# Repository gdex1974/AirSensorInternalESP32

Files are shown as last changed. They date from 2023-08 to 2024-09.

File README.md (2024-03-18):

# Air Quality Sensor - internal unit

## Description
The Air Quality Sensor project contains two parts:
- [External unit](https://github.com/gdex1974/AirSensorExternalESP32) - the main unit placed inside the building
- Internal unit - the unit placed outside the building

The internal unit is equipped with e-Ink display and shows the temperature, humidity and pressure alongside with PM1/2.5/10 measurements from external unit and its own internal sensors. It's powered by 18500 accumulator and receive data from the external unit via Esp-Now transport protocol.
This unit is based on Firebeetle-ESP32 board, with the firmware based on ESP-IDF framework. The board was chosen due to 32K oscillator for RTC and low power consumption.

## Hardware

- [Firebeetle-ESP32](https://wiki.dfrobot.com/FireBeetle_ESP32_IOT_Microcontroller(V3.0)__Supports_Wi-Fi_&_Bluetooth__SKU__DFR0478) main microcontroller board
- [SPS30](https://botland.store/air-quality-sensors/15062-dust-air-sensor-sps30-pm10-pm25-pm4--5904422366094.html) particulate matter sensor
- [BME280](https://botland.store/pressure-sensors/11803-bme280-humidity-temperature-and-pressure-5904422366179.html) temperature, humidity and pressure sensor
- [Pololu Mini MOSFET Switch](https://www.pololu.com/product/2810) low voltage module switch
- [Pololu U1V10F5](https://www.pololu.com/product/2564) 5V step-up module
- [18650 battery case](https://botland.store/battery-holders/5242-cell-holder-for-1x-18650-5904422333393.html) 18650 battery case
- [18650 accumulator](https://botland.store/li-ion-batteries/15216-18650-li-ion-samsung-inr18650-35e-3500mah-5904422343071.html) 18650 accumulator
- [3,7" WaveShare e-ink display](https://www.waveshare.com/wiki/3.7inch_e-Paper_HAT) 3,7" WaveShare e-ink display
- [2x20 2,54mm DIP header](https://www.kiwi-electronics.com/en/40-pin-male-header-2x20-1174) 2x20 2,54mm DIP header
- [Prototyping board 40x60mm 2,54mm pitch](https://www.kiwi-electronics.com/en/prototyping-board-4x6cm-2-54mm-pitch-3828) Prototype board 40x60mm 2,54mm pitch

## Software

- [esp-idf](https://github.com/espressif/esp-idf/releases/tag/v4.4.5) main framework
- [general-support-library](https://github.com/gdex1974/embedded-general-support-library) common embedded library
- [SimpleDrivers](https://github.com/gdex1974/embedded-simple-drivers) simple embedded drivers for SPS30 and BME280 sensors

## Setup

All parts of the unit are fixed on frame and covered by external cover. The frame is designed to fit the Firebeetle board, switch, step-up converter, BME280 and SPS30 sensors. It's attached to battery case and the whole module is placed into the external cover. The fame and cover parts are 3D printed.
Connection schema:
- SPS30 sensor is connected to the UART2 port of the Firebeetle board.
  - `VCC` pin of the sensor is connected to the +5V output of the step-up converter
  - `RX` pin of the sensor is connected to the `IO26` pin of the board
  - `TX` pin of the sensor is connected to the `IO27` pin of the board
  - `SEL` pin of the sensor is not connected
  - `GND` pin of the sensor is connected to the `GND` pin of the board
- BME280 module is connected to the I2C port of the Firebeetle board
  - `SDA` pin of the sensor is connected to the `IO21` pin of the board
  - `SCL` pin of the sensor is connected to the `IO22` pin of the board
  - `GND` pin of the sensor is connected to the `GND` pin of the board
  - `VCC` pin of the sensor is connected to the `3V3` pin of the board
- Pololu 2810 switch is mounted under the main board:
  - `GND` connected to the GND pin of the board
  - `Enable` pin connected to the IO13 pin of the Firebeetle board
  - `VIN` pin connected to the battery+ of the Firebeetle board
  - `VOUT` pin connected to the + input of the step-up converter
- step-up converter's is fixed into separated place on the frame under the board
  - `VIN` is connected to the VBAT pin of the Firebeetle board
  - `GND` is connected to the GND pin of the Firebeetle board
  - `VOUT`is connected to the VCC pin of the SPS30 sensor
- e-ink display is connected to the SPI port of the Firebeetle board. It's attached to the 2x20 DIP header soldered on the protoboard to emulate the Raspberry PI 40-pin header. To make it, the protoboard have to be cut to the 3x20 size and the header should be soldered to the board. The cords to the display are soldered to the socket (the 1st pin is top left):
  - `CS`: pin 24 of the header is connected to the `IO25` pin of the board
  - `DC`: pin 22 of the header is connected to the `IO4` pin of the board
  - `RST`: pin 11 of the header is connected to the `IO15` pin of the board
  - `BUSY`: pin 18 of the header is connected to the `IO16` pin of the board
  - `CLK`: pin 23 of the header is connected to the `IO18` pin of the board
  - `DIN`: pin 19 of the header is connected to the `IO23` pin of the board
  - `GND` pin 6 (possibly 9, 14, 20, 25, 30, 34, 39) of the socket is connected to the `GND` pin of the board
  - `3.3V` pin 1 of the socket is connected to the `3V3` pin of the board

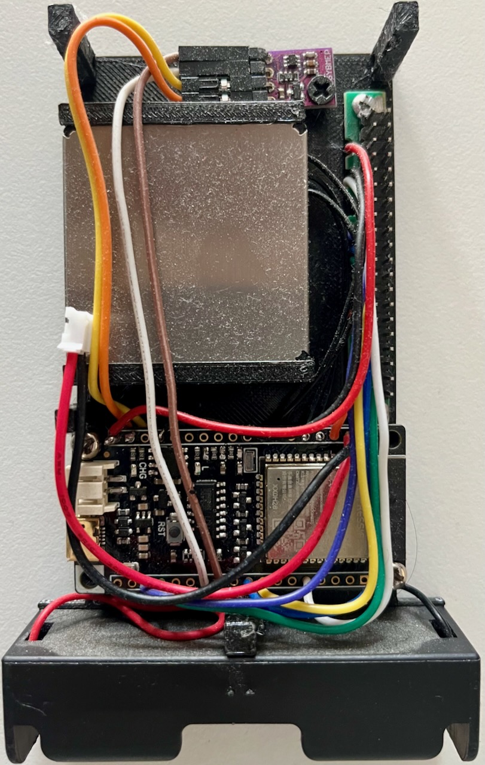
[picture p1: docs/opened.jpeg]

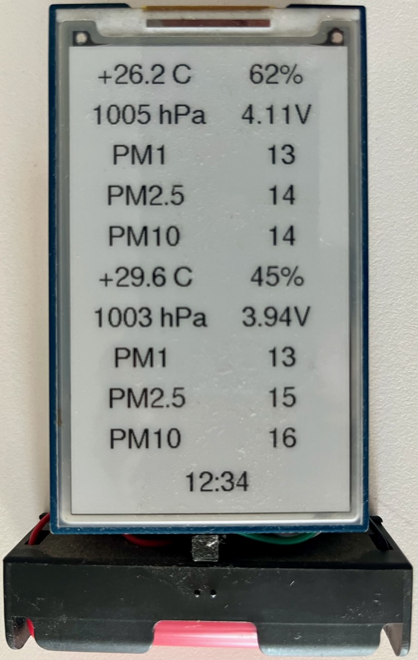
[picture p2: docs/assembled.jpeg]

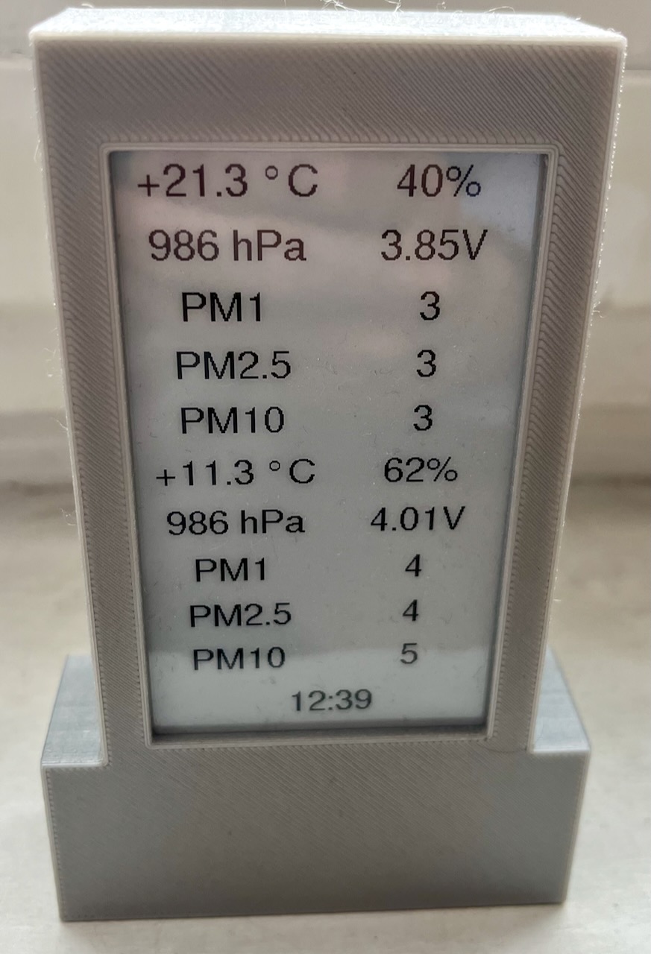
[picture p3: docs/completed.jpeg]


## Firmware

The firmware is based on ESP-IDF framework (tested version is 4.4.5) and is written in C++ language. The main task is to show the data from internal sensors alongside with the ones received from the external unit via Esp-Now protocol. The firmware is divided into several modules:

- components - contains the code of the external unit
  - general-support library - contains the code for general support functions, obtained from this repository.
  - SimpleDrivers - contains the code for the SPS30, BME280 and e-Ink display drivers, obtained from this repository.
- main - contains the main code of the external unit's firmware
  - AppConfig - contains the code for the application's configuration
  - AppMain - contains the app_main() function and hosts the controller object
  - DustMonitorController - contains the code for the controller class handling the main logic of the firmware
  - DustMonitorView - contains the code for the class providing the data for the e-Ink display
  - EspNowTransport - contains the code for the communication with the main unit based on Esp-Now protocol
  - PTHProvider - contains the code for the class providing the data from BME280 sensor
  - SPS30DataProvider - contains the code for the class providing the data from SPS30 sensor
  - WiFiManager - contains the code for the class providing the Wi-Fi connection management
- CMakeLists.txt - main CMake file for the firmware
- sdkconfig - default configuration file for the ESP-IDF framework.

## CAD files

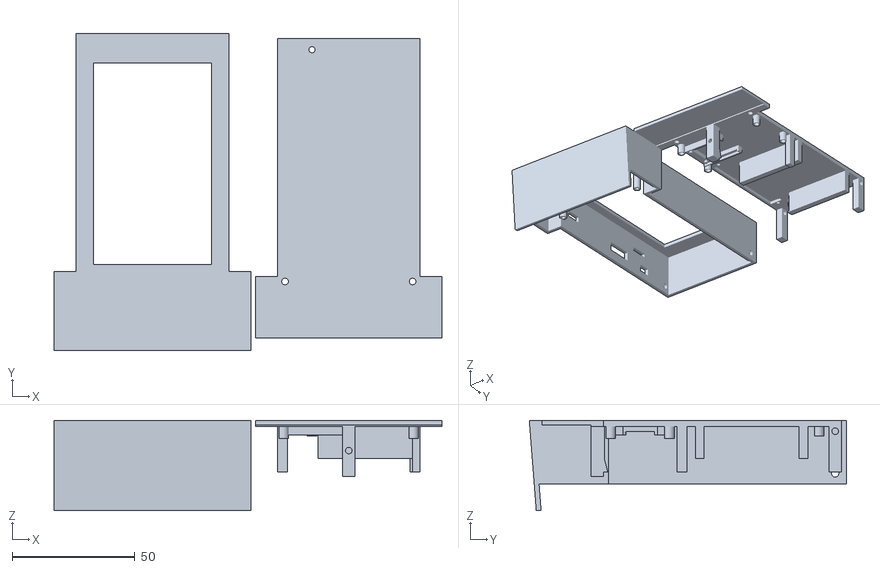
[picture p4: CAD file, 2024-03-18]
docs/PMSensorCaseInternal.stl
158.2 x 129.4 x 36.8

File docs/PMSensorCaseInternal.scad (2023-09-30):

$fn=180;

module fireBeetleD()
{
    height = 7;
    width = 29;
    length = 58;
    radius = 2;
    delta = 5;
    x = length - radius;
    y = width - radius;
    z = height;
    hole_diameter = 2.7;
    linear_extrude(height = z) hull() {
        translate([(- x / 2) + (radius / 2), (- y / 2) + (radius / 2), 0])
            circle(r = radius);

        translate([(x / 2) - (radius / 2), (- y / 2) + (radius / 2), 0])
            circle(r = radius);

        translate([(- x / 2) + (radius / 2), (y / 2) - (radius / 2), 0])
            circle(r = radius);

        translate([(x / 2) - (radius / 2), (y / 2) - (radius / 2), 0])
            circle(r = radius);
    }
    translate([-(length - delta) / 2, (width - delta) / 2, height]) cylinder(d = hole_diameter, h = 7, center = false);
    translate([(length - delta) / 2, -(width - delta) / 2, height]) cylinder(d = hole_diameter, h = 7, center = false);
    translate([-(length - delta) / 2, -(width - delta) / 2, height]) cylinder(d = hole_diameter, h = 7, center = false);
    translate([(length - delta) / 2, (width - delta) / 2, height]) cylinder(d = hole_diameter, h = 7, center = false);
}

module bme280i2c()
{
    hole_diameter = 2.7;
    cube([10.5, 13.5, 4]);
    translate([8, 11, - 5]) cylinder(d = hole_diameter, h = 12, center = false);
    translate([3.5, 11, - 10]) cylinder(d = 2.5, h = 8, center = false);
    translate([(10.5 - 8) / 2, 1, 4])cube([8, 2, 6]);
}

module PMS9003M()
{
    x = 40;
    y = 48;
    z = 12;
    radius = 3.5;
    hole_diameter = 2.7;
    union() {
        difference() {
            linear_extrude(height = z) hull() {
                // place 4 circles in the corners, with the given radius
                translate([(- x / 2) + (radius), (- y / 2) + (radius), 0])
                    circle(r = radius);

                translate([(x / 2) - (radius), (- y / 2) + (radius), 0])
                    circle(r = radius);

                translate([(- x / 2) + (radius), (y / 2) - (radius), 0])
                    circle(r = radius);

                translate([(x / 2) - (radius), (y / 2) - (radius), 0])
                    circle(r = radius);
            }
            for (i = [0:1]) rotate([0, 0, i * 180]) translate([(x / 2) - (radius), (y / 2) - (radius), 0]) {
                cylinder(h = 13, r = 3.5, center = false);
                translate([- 3.5, 0, 0])cube([7, 3.5, 13]);
                translate([0, - 3.5, 0]) cube([3.5, 7, 13]);
            }
        }
        translate([0, 0, (z - 1) / 2])linear_extrude(height = 1) hull() {
            // place 4 circles in the corners, with the given radius
            translate([(- x / 2) + (radius), (- y / 2) + (radius), 0])
                circle(r = radius);

            translate([(x / 2) - (radius), (- y / 2) + (radius), 0])
                circle(r = radius);

            translate([(- x / 2) + (radius), (y / 2) - (radius), 0])
                circle(r = radius);

            translate([(x / 2) - (radius), (y / 2) - (radius), 0])
                circle(r = radius);
        }
        for (i = [0:1]) rotate([0, 0, i * 180]) translate([(x / 2) - (radius), (y / 2) - (radius), 0]) {
            cylinder(h = 12, d = hole_diameter, center = false);
        }
        translate([x / 2 - 28 - 4, - y / 2 + 7.5, 12]) cube([8, 9, 5]);
        translate([x / 2 - 28, 36 - y / 2, 12]) difference() {
            cylinder(d = 20, h = 5);
            rotate([0, 0, 135])translate([- 2.5, 0, - 1])cube([5, 10, 10]);
            translate([0, 0, - 1])cylinder(d = 12, h = 7);
        }
    }
}

sps30Width = 40.9;
sps30Depth = 40.8;
sps30Height = 12.5;
module sps30()
{
    cube([sps30Depth, sps30Width, sps30Height]);
    bigInletWidth = 6.6;
    bigInletHeight = 3.8;
    translate([sps30Depth, sps30Width - bigInletWidth - 2.2, 8.2])cube([4, bigInletWidth, bigInletHeight]); // big inlet
    smallInletWidth = 10;
    smallInletHeight = 2;
    translate([sps30Depth, sps30Width - smallInletWidth - 5.2, - 0.2])cube([4, smallInletWidth, smallInletHeight]);
    // small inlet
    outletWidth = 14.8;
    outletHeight = 5;
    translate([sps30Depth, 5.5, 5.8])cube([4, outletWidth, outletHeight]); //outlet
}


module stepup5V()
{
    union() {
        cube([18, 26, 1.5]);//3.8
        translate([2, - 1, - 1.5 - 1.4 + 0.6]) cube([14, 21.7, 2.3 + 1.4]);
    }
}

module epd37()
{
    plateHeight = 1.8;
    shift = 0.6;
    union() {
        cube([58, 96.5, plateHeight]);
        translate([5, 5, - 3]) cube([48, 82, 3]);
        translate([52, 49.4, plateHeight]) cube([5.7, 20, 6]);
        translate([shift, 33.6, plateHeight]) cube([5, 51.2, 20.2]);
        translate([shift, 33.6 - (60 - 51.2) / 2, 0.3 + 18.6]) cube([7, 60, 1.5]);
        translate([shift + 4.2, 33.6 - (60 - 51.2) / 2 + 3, 0.3 + 18.6 - 5.5])cylinder(d = 1.8, h = 9);
        translate([shift + 4.2, 33.6 - (60 - 51.2) / 2 + 3 + 54, 0.3 + 18.6 - 5.5])cylinder(d = 1.8, h = 9);
        translate([shift + 4.8, 33.6, 0.3 + 18.6 + 1.5]) cube([3, 51.2, 1.4]);
    }
}

module LiIonCase()
{
    base = 55;
    width = 76;
    height = 20;
    depth = 21;
    hole_diameter = 2.7;
    cube([depth, width, height]);
    translate([depth / 2, width / 2, - 6]) cylinder(d = hole_diameter, h = 6);
}

basePlateThickness = 2.4;
internalHeight = 122;
internalBatteryHeight = 25;
internalBatteryWidth = 76;
internalMainWidth = 58;
internalSpaceHeignt = 21.6;
basePlateShiftZ = 18;

module mainFrame()
difference() {
    union() {
        color("magenta") translate([0, - internalBatteryHeight, basePlateShiftZ])cube([internalMainWidth,
            internalHeight, basePlateThickness]);
        color("magenta") translate([- 9, - internalBatteryHeight, basePlateShiftZ])cube([internalBatteryWidth,
            internalBatteryHeight, basePlateThickness]);
        color("green") translate([2, 5, 14.5]) cube([26, 20, 4]);
        color("magenta") translate([2.5, 3, 13]) {
            cylinder(d = 4, h = 6);
            translate([0, 24, 0]) cylinder(d = 4, h = 6);
            translate([53, 0, 0]) cylinder(d = 4, h = 6);
            translate([53, 24, 0]) cylinder(d = 4, h = 6);
        }

        translate([12.7 + 1.3, 36.7 + 51.3, 12.5]) cylinder(d = 4, h = 6);
        translate([16.5, 38.5 - 1, 4.9]) cube([41.5, 3.6, 13.1]);
        translate([17.5, 35 + 44.8, 4.9]) cube([40.5, 3.6, 13.1]);

        color("magenta") translate([- 1 + 27.5, - 5 - 0.5, - 1.5 + 0.2 - 1.1]) union() {
            cube([5, 6, internalSpaceHeignt]);
            translate([0, 1, 6]) rotate([- 75, 0, 0]) cube([5, 6, 5]);
        }

        color("magenta") {
            translate([0, 92, - 0.6]) cube([4, 5, 20]);
            translate([54, 92, - 0.6]) cube([4, 5, 20]);
            translate([55, 30, - 1]) cube([3, 4, 20]);
        }
    }
    union() {
        color("green")translate([17.2, 40, 5.5]) sps30();
        translate([67, - 5, - basePlateThickness])rotate([0, - 90, 90])LiIonCase();

        translate([1, 0, - basePlateThickness])epd37();

        color("red") translate([29, 15, 6])rotate([0, 0, 0])fireBeetleD();
        color("blue")translate([25, 96, 14])rotate([0, 180, 90]) bme280i2c();

        color("cyan") translate([27, 24, 15.8]) rotate([0, 180, 90]) difference() {
            stepup5V();
            translate([(18 - 1) - 1.2, 24.3 - 1 - 1.5, - 2]) cylinder(d = 1.9, h = 4, center = false);
            translate([(0 + 1) + 1.2, 24.3 - 1 - 1.5, - 2]) cylinder(d = 1.9, h = 4, center = false);
        }
    }
    translate([3, - 2, 11])rotate([0, 0, 0])cylinder(d = 2.7, h = 10);
    translate([55, - 2, 11])rotate([0, 0, 0])cylinder(d = 2.7, h = 10);
    translate([- 1, 94.5, 16])rotate([0, 90, 0])cylinder(d = 2.7, h = 10);
    translate([54, 94.5, 16])rotate([0, 90, 0])cylinder(d = 2.7, h = 10);
}

frontThickness=2;
wallThickness=2;

wallHeight=internalSpaceHeignt+frontThickness+basePlateThickness;
widthDiff2=(internalBatteryWidth-internalMainWidth)/2;
internalGap=0.2;
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

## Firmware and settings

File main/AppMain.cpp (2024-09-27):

#include "DustMonitorController.h"
#include "PersistentStorage.h"
#include "TimeFunctions.h"
#include "AppConfig.h"

#include "SpiDevice.h"
#include "display/EpdInterface.h"

#include "esp32-esp-idf/I2CBus.h"
#include "esp32-esp-idf/PacketUartImpl.h"
#include "esp32-esp-idf/GpioPinDefinition.h"
#include "esp32-esp-idf/SpiBus.h"

#include <esp_attr.h>
#include <esp_sleep.h>
#include <esp_system.h>
#include <soc/rtc.h>
#include <nvs_flash.h>

#include "Debug.h"

namespace
{
constexpr uint32_t rtcCalibrationFactor = (1 << 19);

constexpr uint32_t wakeupDelay = 870000;

RTC_DATA_ATTR std::array<uint8_t, 2048> persistentArray;
std::optional<embedded::PersistentStorage> persistentStorage;

struct MainData
{
    uint32_t wakeupCounter = 0;
    uint32_t rtcCalibrationResult = 0;
    timeval rtcTimeBeforeDeepSleep { .tv_sec = 0, .tv_usec=0 };
    uint64_t rtcSlowTicksBeforeDeepSleep = 0;
};

class ControllersHolder
{
public:
    ControllersHolder(embedded::PersistentStorage &storage, int spiBusNum,
                      int serialPortNum, int8_t address)
            : i2CBus(0)
              , i2CDevice(i2CBus, address)
              , uartDevice(serialPortNum)
              , sps30Uart(uartDevice)
              , spiBus(spiBusNum)
              , spiDevice(spiBus)
              , epdHAL(spiDevice, rstPin, dcPin, csPin, busyPin)
              , controller(storage, sps30Uart, i2CDevice, epdHAL)
    {
        i2CBus.init(AppConfig::SDA, AppConfig::SCL, 400000);
        spiBus.init(sckPin, misoPin, mosiPin);
    }
    DustMonitorController& getController() { return controller; }
private:
    embedded::I2CBus i2CBus;
    embedded::I2CHelper i2CDevice;
    embedded::PacketUart::UartDevice uartDevice;
    embedded::PacketUart sps30Uart;
    embedded::SpiBus spiBus;
    embedded::SpiDevice spiDevice;
    embedded::GpioPinDefinition rstPin{AppConfig::epdResetPin};
    embedded::GpioPinDefinition dcPin{AppConfig::epdDcPin};
    embedded::GpioPinDefinition csPin{AppConfig::epdCsPin};
    embedded::GpioPinDefinition busyPin{AppConfig::epdBusyPin};
    embedded::GpioPinDefinition sckPin{AppConfig::epdSckPin};
    embedded::GpioPinDefinition misoPin{AppConfig::epdMisoPin};
    embedded::GpioPinDefinition mosiPin{AppConfig::epdMosiPin};
    embedded::EpdInterface epdHAL;
    DustMonitorController controller;
};

std::optional<ControllersHolder> controllersHolder;

auto getMicrosecondsTillNextMinute()
{
    const int64_t microSeconds = microsecondsNow();
    const int64_t wholeMinutePast = (microSeconds / microsecondsInMinute) * microsecondsInMinute;
    return wholeMinutePast + microsecondsInMinute - microSeconds;
}

uint32_t calculateHibernationDelay()
{
    const auto timeTillNextMinute = getMicrosecondsTillNextMinute();
    DEBUG_LOG("Time till next minute:" << timeTillNextMinute)
    uint32_t delayTime;
    if (timeTillNextMinute <= wakeupDelay)
    {
        DEBUG_LOG("Too short delay " << timeTillNextMinute << " (" << wakeupDelay << "), skipping next wakeup")
        delayTime = microsecondsInMinute + timeTillNextMinute - wakeupDelay;
    }
    else
    {
        delayTime = timeTillNextMinute - wakeupDelay;
    }
    return delayTime;
}

uint32_t calibrateRtcOscillator()
{
    const uint32_t calCount = 1000;
    uint32_t caliVal;

    for (int i = 0; i < 5; ++i)
    {
        caliVal = rtc_clk_cal(RTC_CAL_32K_XTAL, calCount);
        DEBUG_LOG("Calibration " << i << ": " << embedded::BufferedOut::precision { 3 } << rtcCalibrationFactor * 1000.0f / (float)caliVal << " kHz")
    }
    return caliVal;
}

void adjustClock(MainData &mainData)
{
    if (mainData.rtcCalibrationResult != 0)
    {
        auto newCircles = rtc_time_get();
        uint64_t diffTicks = newCircles - mainData.rtcSlowTicksBeforeDeepSleep;
        auto diffMicroseconds = diffTicks * mainData.rtcCalibrationResult / rtcCalibrationFactor;
        auto timeMicroseconds =
                mainData.rtcTimeBeforeDeepSleep.tv_sec * 1000000ull +
                mainData.rtcTimeBeforeDeepSleep.tv_usec;
        timeMicroseconds += diffMicroseconds;
        const uint32_t seconds = timeMicroseconds / 1000000;
        const uint32_t microseconds = timeMicroseconds - seconds * 1000000;
        timeval timeVal { .tv_sec = static_cast<time_t>(seconds), .tv_usec= static_cast<suseconds_t>(microseconds) };
        settimeofday(&timeVal, nullptr);
        DEBUG_LOG("Calculated sleep time : " << diffMicroseconds)
    }
}

} // namespace

void setup()
{
    persistentStorage.emplace(persistentArray,esp_reset_reason() != ESP_RST_DEEPSLEEP);

    auto mainData = persistentStorage->get<MainData>("main");
    if (!mainData)
    {
        mainData.emplace();
    }

    setenv("TZ", AppConfig::timeZone.begin(), 1);
    tzset();

    const bool initialSetup = mainData->wakeupCounter++ == 0;
#ifdef DEBUG_SERIAL_OUT
    embedded::PacketUart::UartDevice::init(0, AppConfig::serial1RxPin, AppConfig::serial1TxPin, 115200);
#endif
    embedded::PacketUart::UartDevice::init(2, AppConfig::serial2RxPin, AppConfig::serial2TxPin, 115200);
    embedded::GpioPinDefinition ledPinDefinition { AppConfig::ledPin };
    embedded::GpioDigitalPin ledPin(ledPinDefinition);
    ledPin.init();
    ledPin.reset();
    controllersHolder.emplace(*persistentStorage, 2, 2, AppConfig::bme280Address);
    if (initialSetup)
    {
        DEBUG_LOG("Initial setup")
        mainData->rtcCalibrationResult = calibrateRtcOscillator();
    }
    else
    {
        adjustClock(*mainData);
    }
    if (!controllersHolder->getController().setup(!initialSetup))
    {
        DEBUG_LOG("Setup failed")
    }
    persistentStorage->set("main", *mainData);
}

[[noreturn]] void process()
{
    auto& controller = controllersHolder->getController();
    auto mainData = persistentStorage->get<MainData>("main");
    controller.process();
    controller.hibernate();
    auto delayTime = calculateHibernationDelay();
    if (controller.isMeasuring())
    {
        delayTime = std::min(delayTime, decltype(delayTime)(30 * microsecondsInSecond));
    }
    DEBUG_LOG("Next wakeup in " << delayTime / 1000 << " ms")
    gettimeofday(&mainData->rtcTimeBeforeDeepSleep, nullptr);
    mainData->rtcSlowTicksBeforeDeepSleep = rtc_time_get();
    persistentStorage->set("main", *mainData);
    esp_deep_sleep(delayTime);
}

extern "C" void app_main()
{
    if (const auto ret = nvs_flash_init();
        ret == ESP_ERR_NVS_NO_FREE_PAGES || ret == ESP_ERR_NVS_NEW_VERSION_FOUND)
    {
        ESP_ERROR_CHECK(nvs_flash_erase() );
        ESP_ERROR_CHECK(nvs_flash_init());
    }
    setup();
    process();
}

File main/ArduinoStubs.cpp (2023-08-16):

#include "DustMonitorController.h"
#include "PersistentStorage.h"
#include "TimeFunctions.h"
#include "AppConfig.h"

#include "esp32-arduino/I2CBus.h"
#include "esp32-arduino/PacketUartImpl.h"
#include <WiFi.h>
#include <Wire.h>
#include <SPI.h>
#include <esp_sleep.h>
#include <soc/rtc.h>
#include <esp32-hal-gpio.h>

#include "SpiDevice.h"
#include "esp32-arduino/GpioPinDefinition.h"
#include "eInk/EpdInterface.h"
#include "esp32-arduino/SpiBus.h"

#include "Debug.h"

namespace
{
constexpr uint32_t rtcCalubrationFactor = (1 << 19);

constexpr uint32_t wakeupDelay = 1000000;

RTC_DATA_ATTR std::array<uint8_t, 2048> persistentArray;
std::optional<embedded::PersistentStorage> persistentStorage;

struct MainData
{
    uint32_t wakeupCounter = 0;
    uint32_t rtcCalibrationResult = 0;
    timeval rtcTimeBeforeDeepSleep { .tv_sec = 0, .tv_usec=0 };
    uint64_t rtcSlowTicksBeforeDeepSleep = 0;
};

// for STM32 platform or pure esp-idf UartDevice is a nontrivial class,
// but for Arduino-based platforms Hardware Serial provides enough functionality.
// We can't just make name aliasing to allow forward declaration, so
// we have to use trivial inheritance.
static_assert(sizeof(embedded::PacketUart::UartDevice) == sizeof(HardwareSerial));
static_assert(std::is_base_of_v<HardwareSerial, embedded::PacketUart::UartDevice>);
class ControllersHolder
{
public:
    ControllersHolder(embedded::PersistentStorage &storage, TwoWire& wire, SPIClass &spiClass,
                      HardwareSerial& serial, int8_t address)
            : i2CBus(wire)
              , i2CDevice(i2CBus, address)
              , uart2(static_cast<embedded::PacketUart::UartDevice&>(serial))
              , spiBus(spiClass)
              , spiDevice(spiBus)
              , epdHAL(spiDevice, rstPin, dcPin, csPin, busyPin)
              , controller(storage, uart2, i2CDevice, epdHAL)
    {
    }
    DustMonitorController& getController() { return controller; }
private:
    embedded::I2CBus i2CBus;
    embedded::I2CHelper i2CDevice;
    embedded::PacketUart uart2;
    embedded::SpiBus spiBus;
    embedded::SpiDevice spiDevice;
    embedded::GpioPinDefinition rstPin{AppConfig::epdResetPin};
    embedded::GpioPinDefinition dcPin{AppConfig::epdDcPin};
    embedded::GpioPinDefinition csPin{AppConfig::epdCsPin};
    embedded::GpioPinDefinition busyPin{AppConfig::epdBusyPin};
    embedded::EpdInterface epdHAL;
    DustMonitorController controller;
};

std::optional<ControllersHolder> controllersHolder;

uint32_t calculateHibernationDelay()
{
    const int64_t microSeconds = microsecondsNow();
    const int64_t wholeMinutePast = (microSeconds / microsecondsInMinute) * microsecondsInMinute;
    const auto timeTillNextMinute = wholeMinutePast + microsecondsInMinute - microSeconds;
    DEBUG_LOG("Time till next minute:" << timeTillNextMinute)
    const auto minimumDelay = microsecondsInSecond;
    uint32_t delayTime = 0;
    if (timeTillNextMinute <= minimumDelay)
    {
        DEBUG_LOG("Too short delay " << timeTillNextMinute << " (" << minimumDelay << "), skipping next wakeup")
        delayTime = microsecondsInMinute + timeTillNextMinute - wakeupDelay;
    }
    else
    {
        delayTime = timeTillNextMinute - wakeupDelay;
    }
    return delayTime;
}

uint32_t calibrateRtcOscillator()
{
    const uint32_t cal_count = 1000;
    uint32_t cali_val;

    for (int i = 0; i < 5; ++i)
    {
        cali_val = rtc_clk_cal(RTC_CAL_32K_XTAL, cal_count);
        DEBUG_LOG("Calibration " << i << ": " << embedded::BufferedOut::precision { 3 } << rtcCalubrationFactor * 1000.0f / (float)cali_val
                                << " kHz");
    }
    return cali_val;
}

void adjustClock(MainData &mainData)
{
    if (mainData.rtcCalibrationResult != 0)
    {
        auto newCircles = rtc_time_get();
        uint64_t diffTicks = newCircles - mainData.rtcSlowTicksBeforeDeepSleep;
        auto diffMicroseconds = diffTicks * mainData.rtcCalibrationResult / rtcCalubrationFactor;
        auto timeMicroseconds =
                mainData.rtcTimeBeforeDeepSleep.tv_sec * 1000000ull +
                mainData.rtcTimeBeforeDeepSleep.tv_usec;
        timeMicroseconds += diffMicroseconds;
        const uint32_t seconds = timeMicroseconds / 1000000;
        const uint32_t microseconds = timeMicroseconds - seconds * 1000000;
        timeval tv { .tv_sec = static_cast<time_t>(seconds), .tv_usec= static_cast<suseconds_t>(microseconds) };
        settimeofday(&tv, nullptr);
        DEBUG_LOG("Calculated sleep time : " << diffMicroseconds);
    }
    else
    {
        esp_sync_counters_rtc_and_frc();
    }
}

} // namespace

void setup()
{
    persistentStorage.emplace(persistentArray,esp_reset_reason() != ESP_RST_DEEPSLEEP);

    auto mainData = persistentStorage->get<MainData>("main");
    if (!mainData)
    {
        mainData.emplace();
    }
    if (auto tzData = persistentStorage->get<std::array<char, 33>>("TZ"))
    {
        setenv("TZ", tzData->begin(), 0);
        tzset();
    }
    const bool initialSetup = mainData->wakeupCounter++ == 0;
    Wire.begin(SDA, SCL, 400000);
    Serial.begin(115200);
    Serial2.begin(115200, SERIAL_8N1, AppConfig::serial2RxPin, AppConfig::serial2TxPin);
    SPI.begin();
    embedded::GpioPinDefinition ledPinDefinition { AppConfig::ledPin };
    embedded::GpioDigitalPin ledPin(ledPinDefinition);
    ledPin.init();
    ledPin.reset();
    controllersHolder.emplace(*persistentStorage, Wire, SPI, Serial2, AppConfig::bme280Address);
    if (initialSetup)
    {
        DEBUG_LOG(WiFi.macAddress().c_str());
        DEBUG_LOG("Initial setup")
        mainData->rtcCalibrationResult = calibrateRtcOscillator();
    }
    else
    {
        adjustClock(*mainData);
    }
    if (controllersHolder->getController().setup(!initialSetup))
    {
        DEBUG_LOG("Setup completed");
    }
    else
    {
        DEBUG_LOG("Setup failed");
    }
    persistentStorage->set("main", *mainData);
}
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

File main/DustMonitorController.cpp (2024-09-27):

#include "DustMonitorController.h"
#include "AppConfig.h"

#include "TimeFunctions.h"
#include "PersistentStorage.h"

#include "AnalogPin.h"
#include "esp32-esp-idf/GpioPinDefinition.h"

#include <driver/rtc_io.h>
#include <esp_sntp.h>
#include <freertos/event_groups.h>

#include "Debug.h"
#include "Delays.h"

namespace
{
const std::string_view viewDataTag = "DMC1";
const std::string_view controllerDataTag = "DMC2";
constexpr EventBits_t TIME_SYNC_BIT = BIT0;
constexpr EventBits_t TRANSPORT_COMPLETED_BIT = BIT1;
constexpr EventBits_t VIEW_COMPLETED_BIT = BIT2;
constexpr EventBits_t TIME_TASK_COMPLETED_BIT = BIT3;
constexpr EventBits_t MEASUREMENT_COMPLETED_BIT = BIT4;
constexpr auto secondsInHour = 60*60;

[[nodiscard]]
int readVoltageRaw(uint8_t pin)
{
    embedded::GpioPinDefinition voltagePin { pin };
    const auto voltage = embedded::AnalogPin(voltagePin).singleRead();
    DEBUG_LOG("VoltageRaw is " << voltage)
    return voltage;
}

void initStepUpControl()
{
    const auto stepUpPin = (gpio_num_t)AppConfig::stepUpPin;
    rtc_gpio_init(stepUpPin); //initialize the RTC GPIO port
    rtc_gpio_set_direction(stepUpPin, RTC_GPIO_MODE_OUTPUT_ONLY); //set the port to output only mode
}

void switchStepUpConversion(bool enable)
{
    const auto stepUpPin = (gpio_num_t)AppConfig::stepUpPin;
    rtc_gpio_hold_dis(stepUpPin);
    rtc_gpio_set_level(stepUpPin, enable ? 1 : 0);
    if (enable)
    {
        embedded::delay(20);
    }
}

void holdStepUpConversion()
{
    const auto stepUpPin = (gpio_num_t)AppConfig::stepUpPin;
    rtc_gpio_hold_en(stepUpPin);
}

EventGroupHandle_t eventGroup = nullptr;

void time_sync_notification_cb(struct timeval *)
{
    DEBUG_LOG("Notification of a time synchronization event")
    xEventGroupSetBits(eventGroup, TIME_SYNC_BIT);
}

}

void DustMonitorController::timeSyncTask(void* pvParameters)
{
    reinterpret_cast<DustMonitorController*>(pvParameters)->timeSyncTask();
}

[[noreturn]] void DustMonitorController::timeSyncTask()
{
    while (true)
    {
        xEventGroupClearBits(eventGroup, TIME_TASK_COMPLETED_BIT);
        const bool relevantTime = isTimeSyncronized();
        const auto currentTime = time(nullptr);
        bool refreshRequired = relevantTime && (controllerData.lastTimeSyncTime + 12 * secondsInHour < currentTime)
                && getLocalTime(currentTime).tm_hour == 0 && controllerData.sps30Status != SPS30Status::Measuring;

        if (refreshRequired)
        {
            DEBUG_LOG("Time syncronization is required, waiting for transport completion")
            transport.init({ eventGroup, TRANSPORT_COMPLETED_BIT});
            xEventGroupWaitBits(eventGroup, TRANSPORT_COMPLETED_BIT, pdFALSE, pdTRUE, portMAX_DELAY);
            transport.hibernate();
            DEBUG_LOG("Transport completed")
        }
        if (!relevantTime || refreshRequired)
        {
            if (const auto state = wifiManager.getState(); state == WiFiManager::State::Stopped ||
                                                           state == WiFiManager::State::NotInitialized)
            {
                if (refreshRequired || (!isTimeSyncronized() && !timeSyncInitialized))
                {
                    DEBUG_LOG("Starting STA")
                    wifiManager.startSTA(AppConfig::WiFiSSID, AppConfig::WiFiPassword);
                }
            }
            else
            {
                DEBUG_LOG("WiFi manager state: " << static_cast<int>(state))
            }
            if (wifiManager.waitForConnection(20000))
            {
                DEBUG_LOG("Connected to AP")
                xEventGroupClearBits(eventGroup, TIME_SYNC_BIT);
                esp_sntp_setoperatingmode(ESP_SNTP_OPMODE_POLL);
                esp_sntp_setservername(0, AppConfig::ntpServer.data());
                esp_sntp_setservername(1, (char*)nullptr);
                esp_sntp_setservername(2, (char*)nullptr);
                esp_sntp_set_time_sync_notification_cb(time_sync_notification_cb);
                esp_sntp_init();
                xEventGroupWaitBits(eventGroup, TIME_SYNC_BIT, pdFALSE, pdTRUE, portMAX_DELAY);
                esp_sntp_stop();
                controllerData.lastTimeSyncTime = time(nullptr);
            }
            else
            {
                DEBUG_LOG("Failed to connect to WiFi")
            }
            wifiManager.stopSTA();
        }
        if (!transport.init({ eventGroup, TRANSPORT_COMPLETED_BIT}))
        {
            DEBUG_LOG("Failed to initialize ESP-NOW")
        }
        xEventGroupSetBits(eventGroup, TIME_TASK_COMPLETED_BIT);

        vTaskDelay(24*60*60*1000 / portTICK_PERIOD_MS); // sync every day if there is no deep sleep
    }
}

void DustMonitorController::updateDisplayTask(void* pvParameters)
{
    reinterpret_cast<DustMonitorController*>(pvParameters)->updateDisplayTask();
}

[[noreturn]] void DustMonitorController::updateDisplayTask()
{
    timeval timeVal;
    gettimeofday(&timeVal, nullptr);
    const auto timeSeconds = timeVal.tv_sec;
    if (const auto seconds = timeSeconds % 60; seconds != 0)
    {
        vTaskDelay(((60 - seconds)*1000 - timeVal.tv_usec / 1000) / portTICK_PERIOD_MS + 1);
    }
    auto lastUpdateTime = xTaskGetTickCount();
    while (true)
    {
        view.updateView();
        xEventGroupSetBits(eventGroup, VIEW_COMPLETED_BIT);
        xTaskDelayUntil(&lastUpdateTime, 60*1000 / portTICK_PERIOD_MS);
    }
}

void DustMonitorController::measurementTask(void* pvParameters)
{
    reinterpret_cast<DustMonitorController*>(pvParameters)->measurementTask();
}
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

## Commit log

2023-08-16 Add first viable version
    [InternalUnitFrame.scad, InternalUnitFrame.stl]
2023-08-26 Make the version without Arduino dependency the main one. (#4)
    * Use updated BME280 driver
    * Use AnalogPin::singleRead();
    * Pull general-suppport-library
    * Remove Arduino component
    * Fix example config
    * Fix example config
    * Fix submodile paths
    ---------
    [AppMain.cpp, DustMonitorController.cpp]
2023-09-03 Use components without dependency on Arduino framework. (#5)
    * Use components without dependency on Arduino framework.
    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
    [DustMonitorController.cpp]
2023-09-30 Pull changes from master branch (#6)
    * Switch logic to wake up after 30 seconds of PM measurement to stop it.
    * Fix incompatibility after merge.
    * Pull submodules
    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
    [InternalUnitFrame.scad]
2023-09-30 Merge master branch to main (#7)
    * Add 8-bit font to proper show the degree sign.
    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
2024-03-18 Merge incoming changes from master to main (#9)
    * Add .gitlab-ci.yml file
    * Update .gitlab-ci.yml file
    * Set secret detection config
    * Use embedded binary font files instead of generated C++ include file
    * External flags support
    * Update sdkconfig to 4.4.6
    * Update documentati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
    [InternalUnitFrame.stl, PMSensorCaseInternal.scad, PMSensorCaseInternal.stl]
2024-09-27 Rebase and merge (#11)
    * Update documentation
    * Update sdkconfig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
    [AppMain.cpp, DustMonitorController.cpp]
2024-09-27 Pull master (#12)
    * Update sdkconfig to ve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
